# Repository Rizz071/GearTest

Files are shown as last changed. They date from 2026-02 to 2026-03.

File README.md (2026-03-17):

# GearTest

**Тестовый стенд для 3D-печатных шестерёнок**
<p align="left">
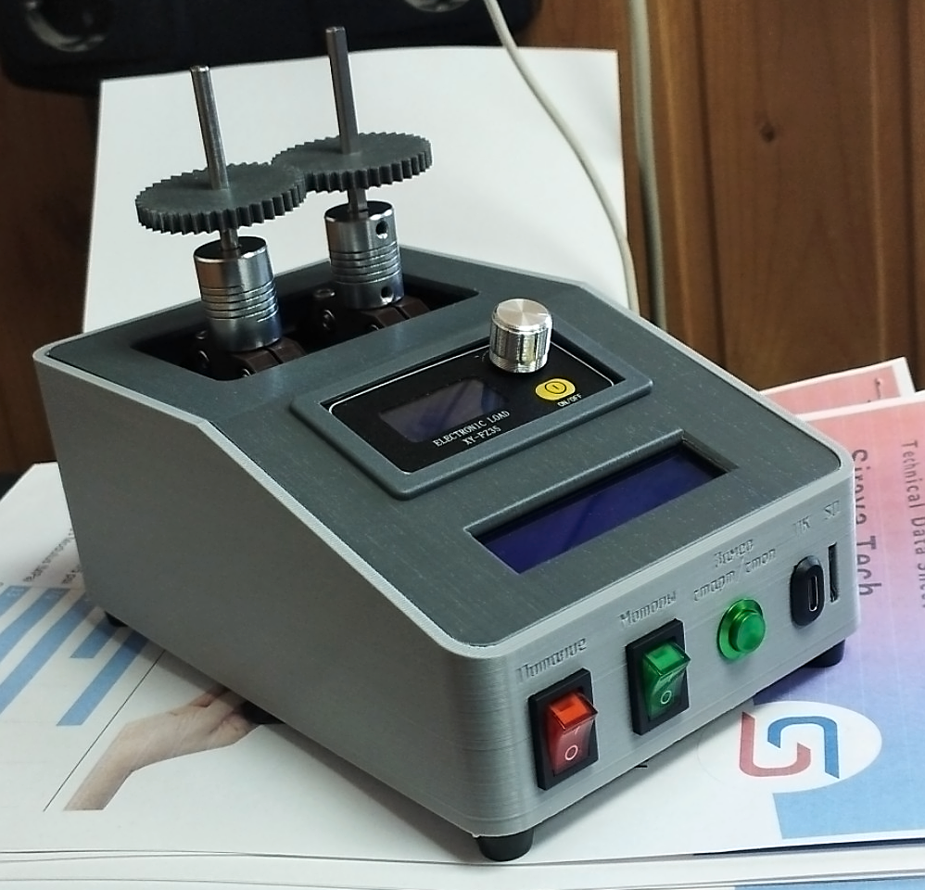
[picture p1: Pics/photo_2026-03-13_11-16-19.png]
  
</p>

---

## 🎯 О проекте

**GearTest** — это полностью открытый тестовый стенд, предназначенный для **испытания 3D-печатных шестерёнок на износ до полного отказа**.

**Главная цель**: довести пару шестерён до разрыва зацепления зубьев и точно зафиксировать момент разрушения с подробным **логированием всех параметров** в десктопное приложение на ПК.

Это позволяет объективно сравнивать долговечность разных материалов (PLA, PETG, ABS, ASA, Nylon и др.), профилей зубьев, параметров печати и постобработки.

---

## ✨ Ключевые возможности

- ✅ Автоматическая остановка при разрушении зацепления  
- ✅ Точный подсчёт времени работы до отказа  
- ✅ Логирование в реальном времени (время, нагрузка)  
- ✅ Удобное десктопное приложение для визуализации и анализа  
- ✅ Сохранение отчётов в CSV + построение графиков  
- ✅ Полностью открытый проект (hardware + software + CAD)

---

## 🛠️ Как это работает

1. В стенд устанавливается пара тестируемых шестерён  
2. Приводной мотор запускает непрерывное вращение под заданной нагрузкой  
3. Система мониторит параметры в реальном времени  
4. При разрыве зубьев (резкое изменение нагрузки/обрыв зацепления) испытание останавливается автоматически  
5. Все данные мгновенно сохраняются и отображаются в приложении на ПК

---

## 📁 Структура репозитория

```bash
GearTest/
├── CAD/          # 3D-модели стенда и шестерёнок
├── Docs/         # Полная документация, схемы, методика испытаний
├── GearTest/     # Исходный код
├── images/       # Фото и скриншоты
├── results/      # Примеры протоколов испытаний (появится позже)
└── LICENSE       # GNU GPL v3.0

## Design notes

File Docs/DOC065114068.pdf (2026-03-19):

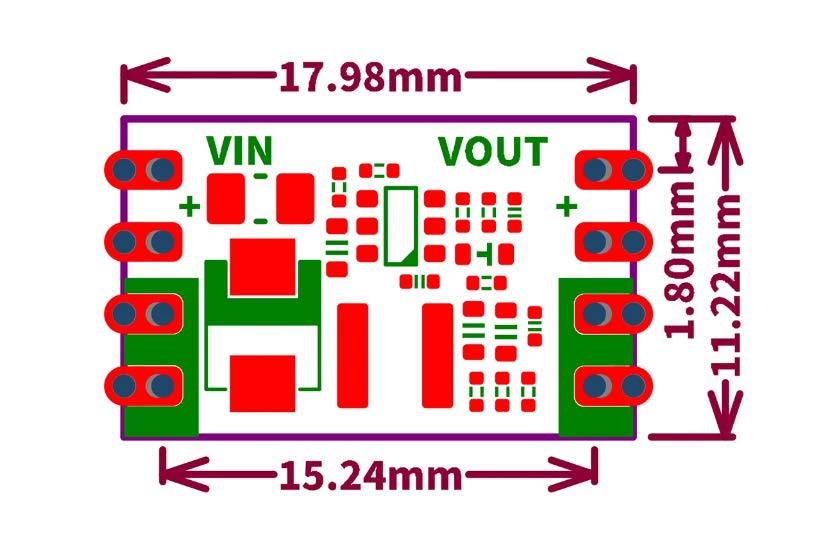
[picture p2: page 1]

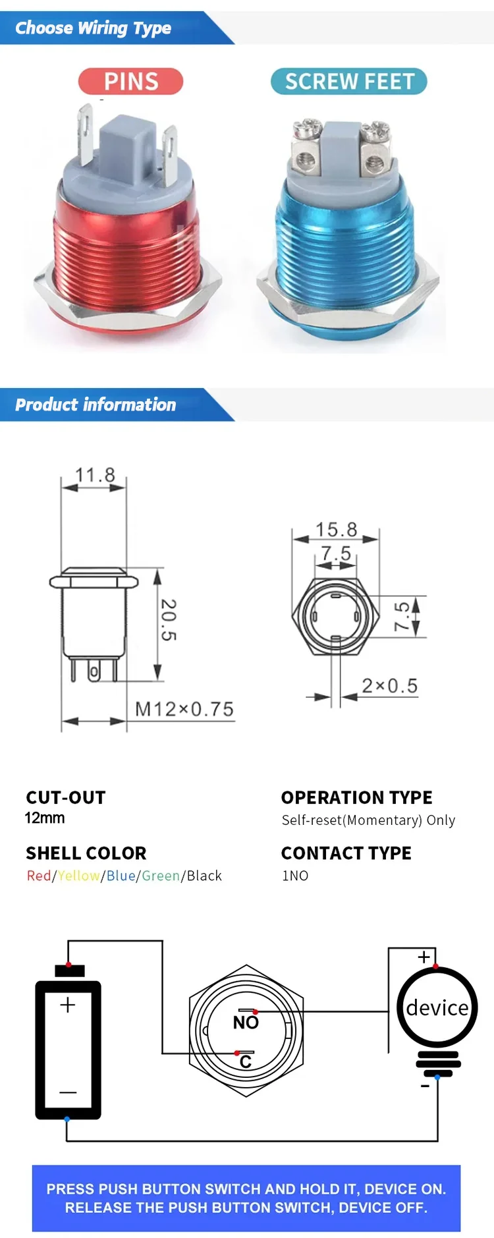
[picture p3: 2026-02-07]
Docs/Button start exper.webp

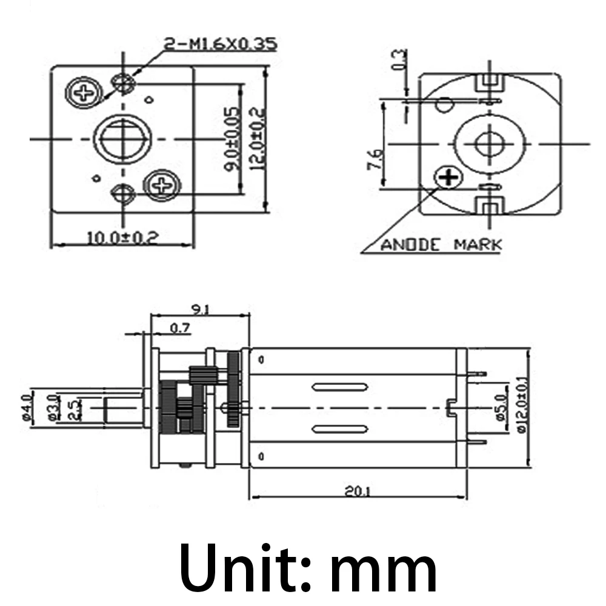
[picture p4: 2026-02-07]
Docs/Sb45f8e3612c54e4f9633423cf06d5a922.webp

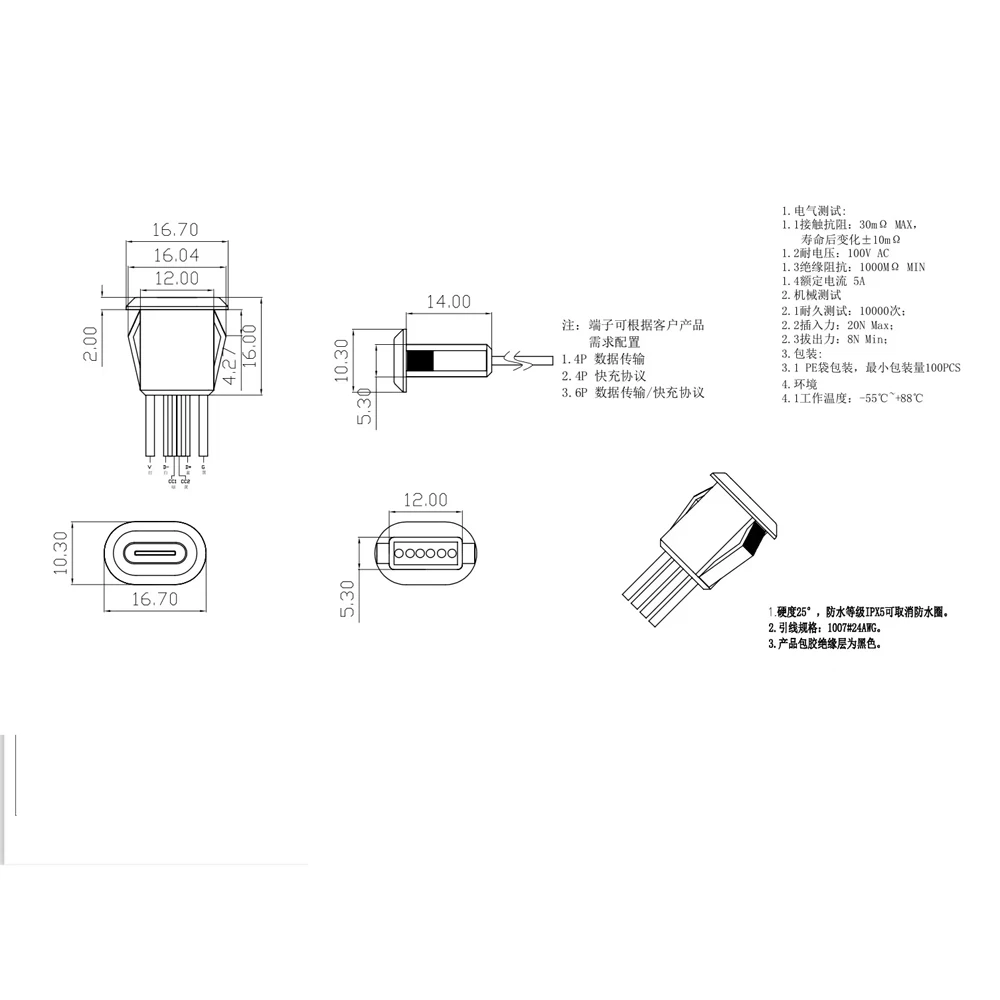
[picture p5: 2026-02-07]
Docs/Sed72e1b84ae94b2fbeed415ec35b5c65x.webp

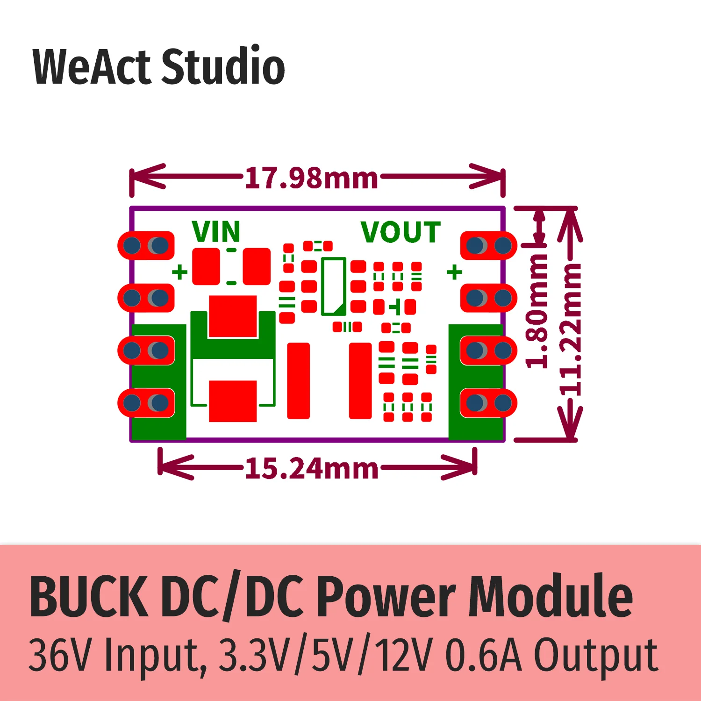
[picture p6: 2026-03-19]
Docs/S60ceae898a6440ccb248dbda5e8abc7ch.png

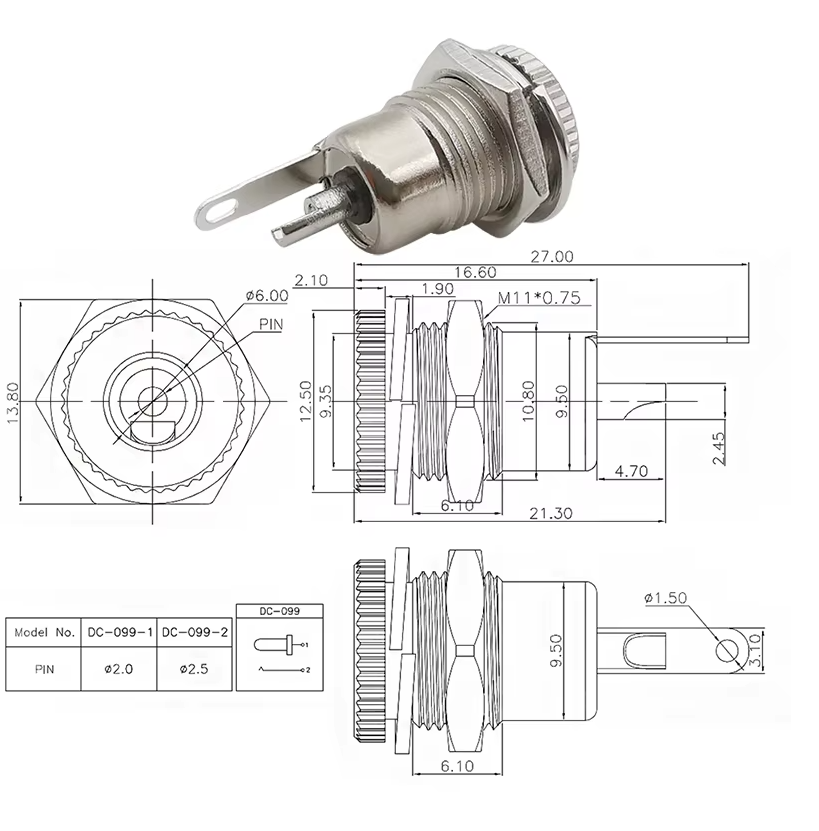
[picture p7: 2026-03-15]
Docs/fem-connector 5.5mm.png

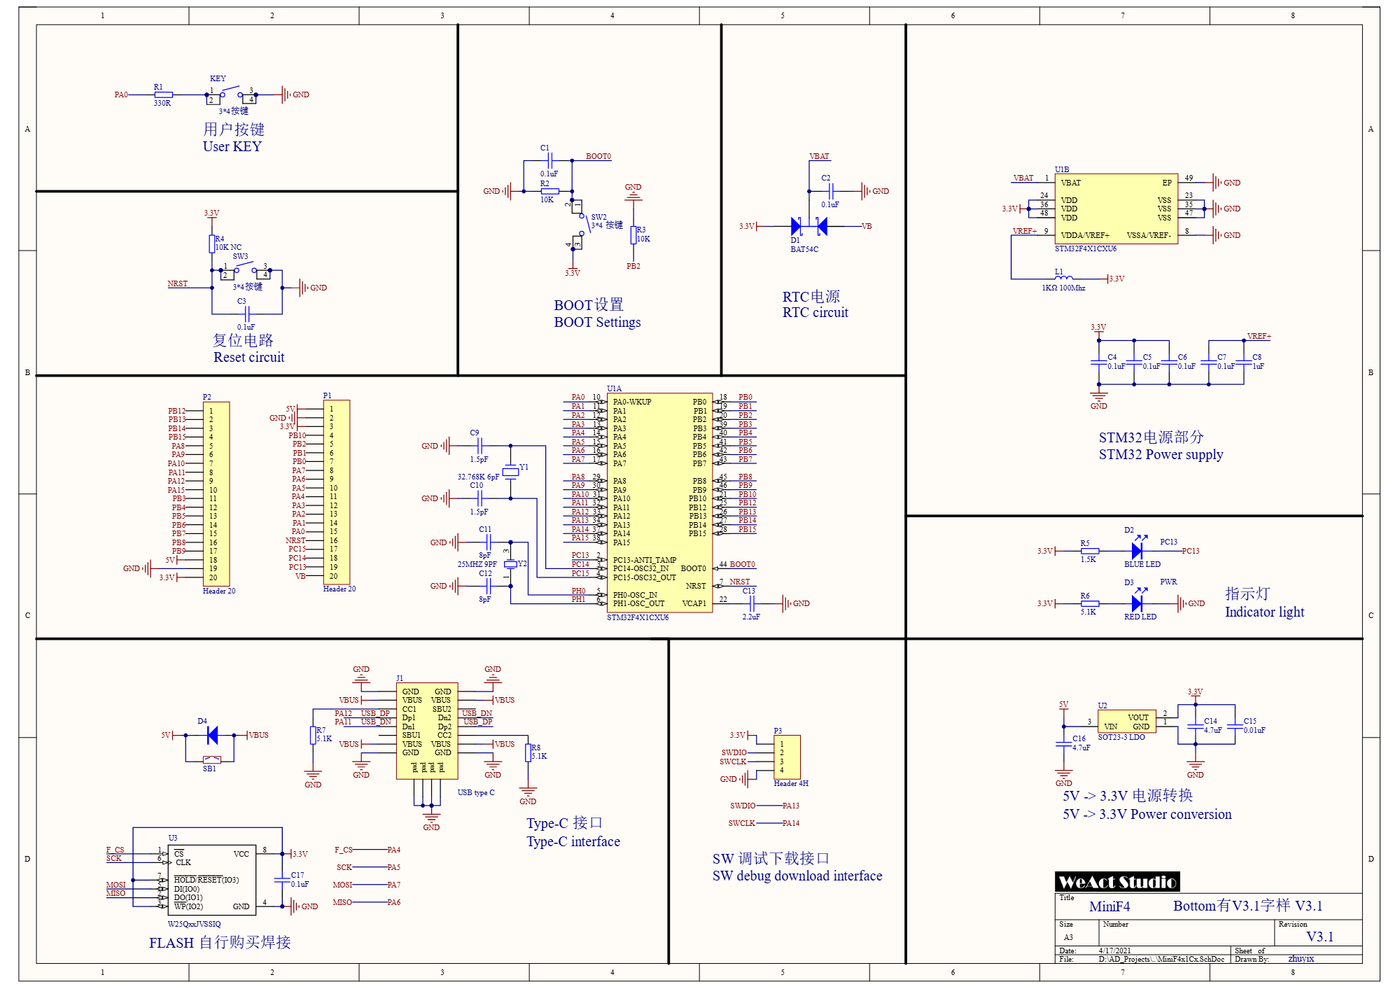
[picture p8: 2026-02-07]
Docs/Без названия.png

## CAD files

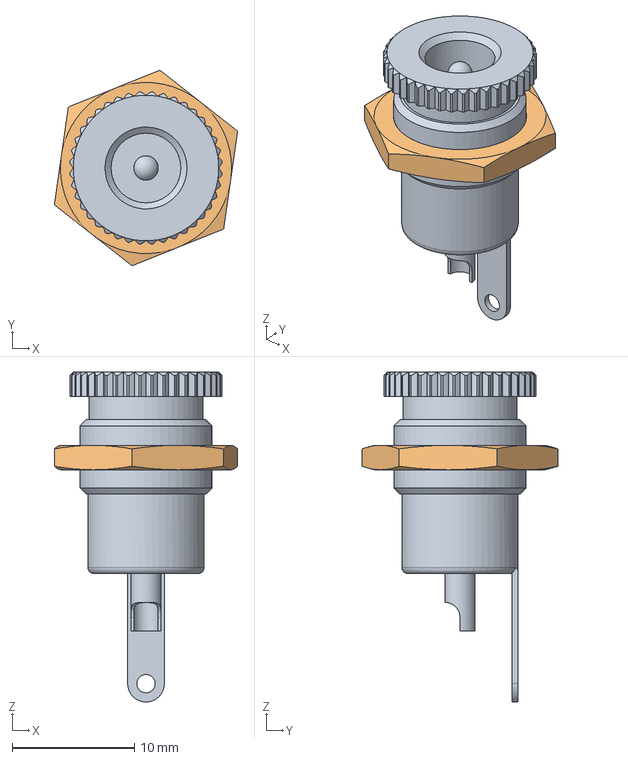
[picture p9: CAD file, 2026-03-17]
CAD/Con_5.5_Assembly.stp
15.0 x 16.0 x 27.0 mm
DC-Connector 5,5mm female
Nut M11x0.75

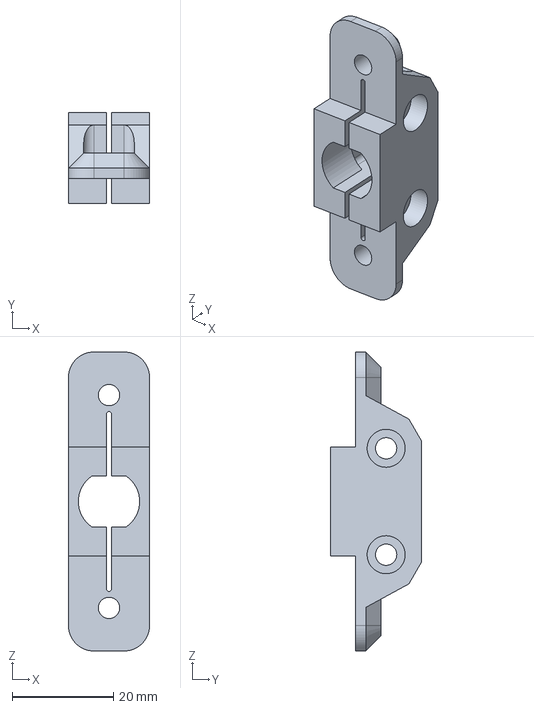
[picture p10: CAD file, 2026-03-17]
CAD/3D print/Держатель мотора скользящий-2.stp
16.0 x 18.0 x 59.0 mm

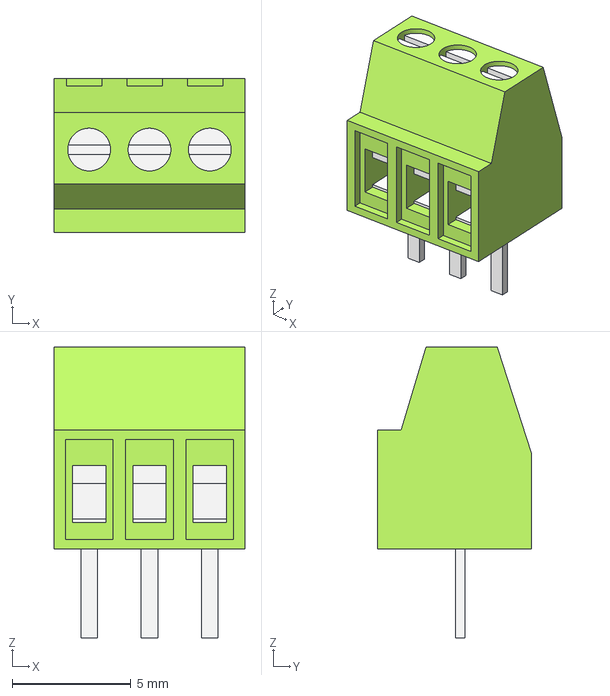
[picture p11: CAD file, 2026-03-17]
CAD/KF128-2.54-3P.step
8.02 x 6.50 x 12.3 mm
Housing
PlasticBody

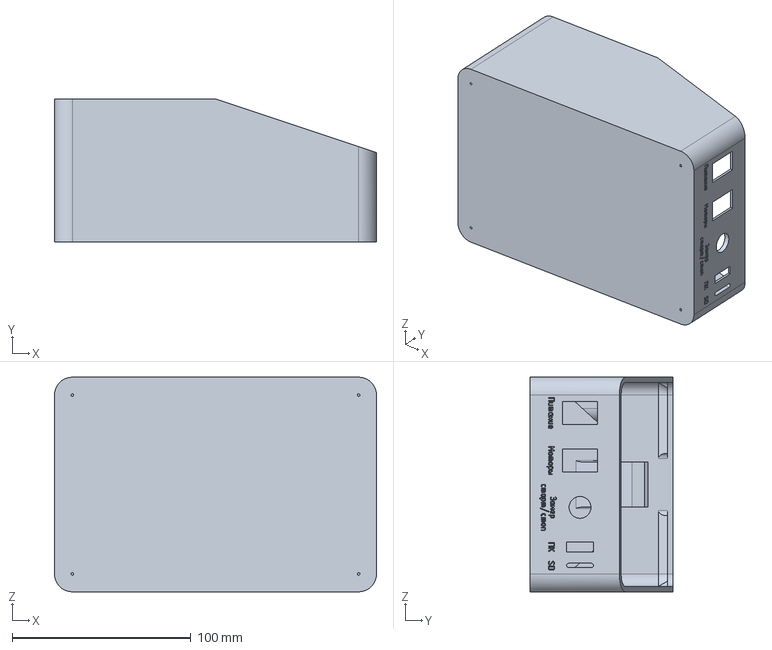
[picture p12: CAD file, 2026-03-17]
CAD/3D print/Основание корпуса.stp
180.0 x 80.0 x 120.0 mm

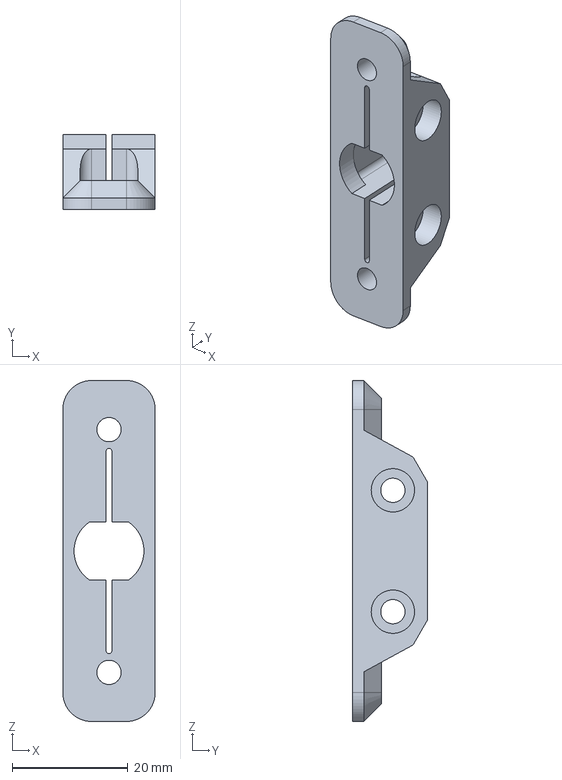
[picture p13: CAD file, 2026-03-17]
CAD/3D print/Держатель мотора скользящий.stp
16.0 x 13.0 x 59.0 mm

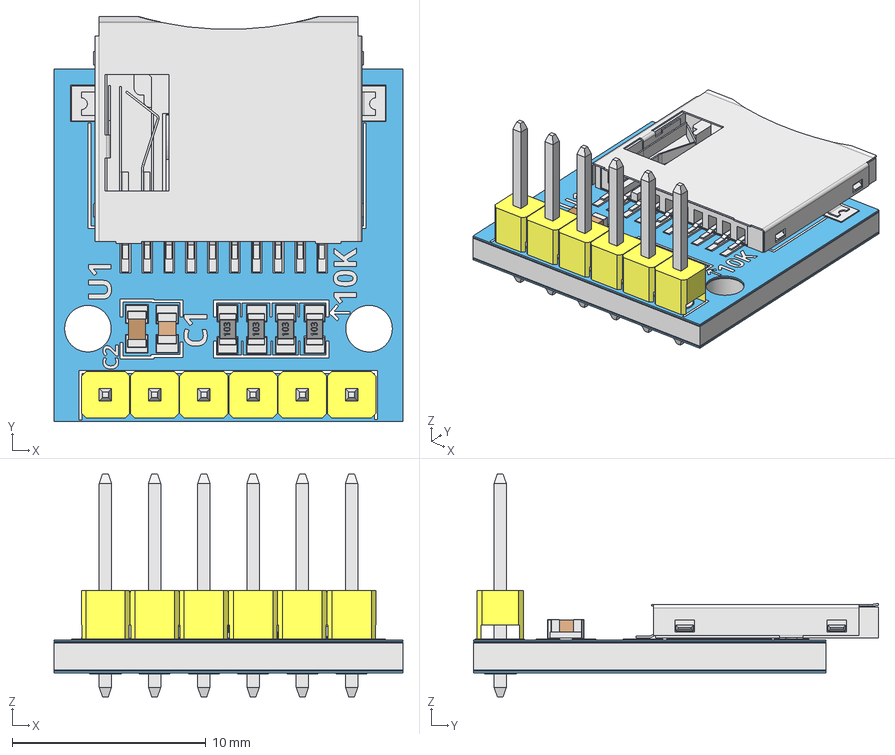
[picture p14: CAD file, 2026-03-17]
CAD/microSD_module_pls.step
18.0 x 20.9 x 11.5 mm
board_body
mask_up
mask_bt
metal_bt
metal_up
silk001
silk002
silk003
silk004
silk005
silk007
silk008
10K
U1
C1
C2
3V3
CS
MOSI
CLK001
MISO
GND001
sd_cover
conn001
conn002
conn003
conn004
conn005
conn006
conn007
conn008
conn009
conn010
pin011
label006
ShapeString009
pin012
pin013
label007
ShapeString010
pin014
pin015
label008
ShapeString011
pin016
pin017
label009
ShapeString012
pin018
contact019
contact020
contact033
contact034
Frame
Pin001
Pin002
Pin003
Pin004
Pin011
Pin012

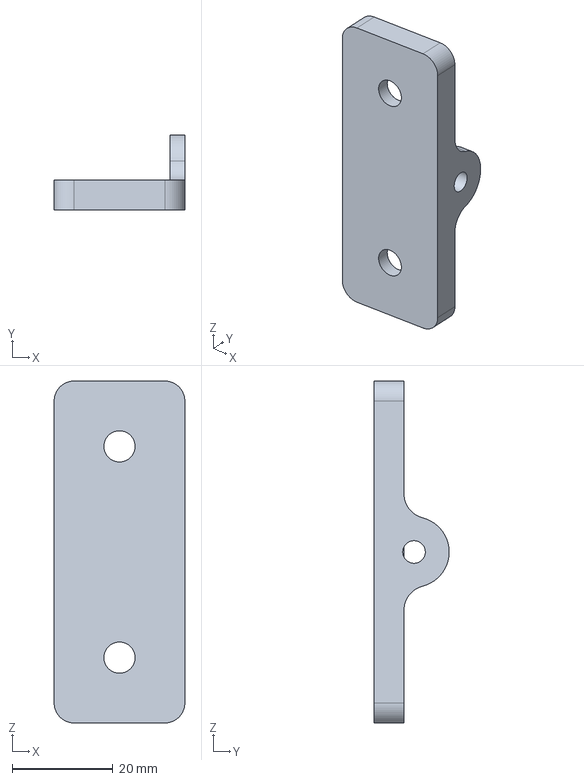
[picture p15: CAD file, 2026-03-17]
CAD/3D print/Скоба шасси.stp
26.0 x 15.0 x 68.0 mm

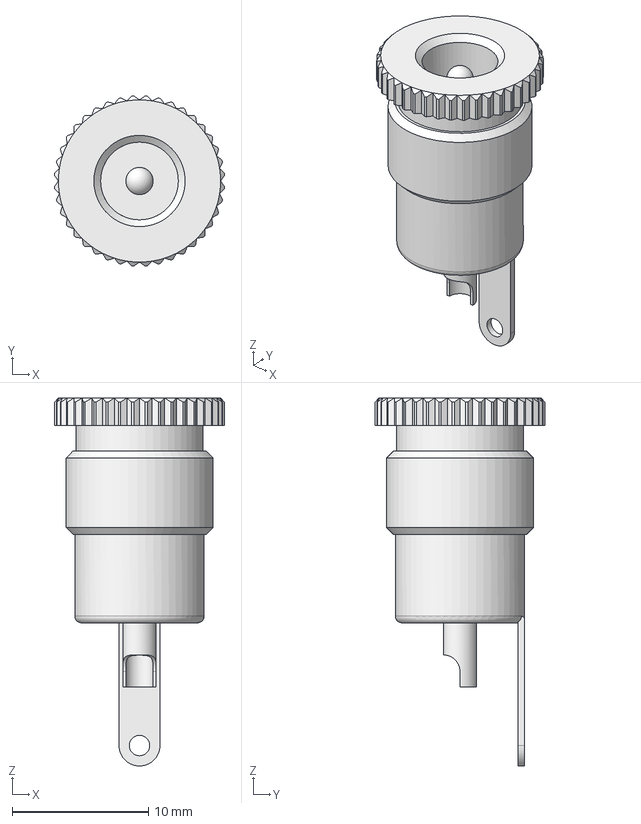
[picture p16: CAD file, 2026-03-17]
CAD/DC-Connector 5,5mm female.stp
12.5 x 12.5 x 27.0 mm

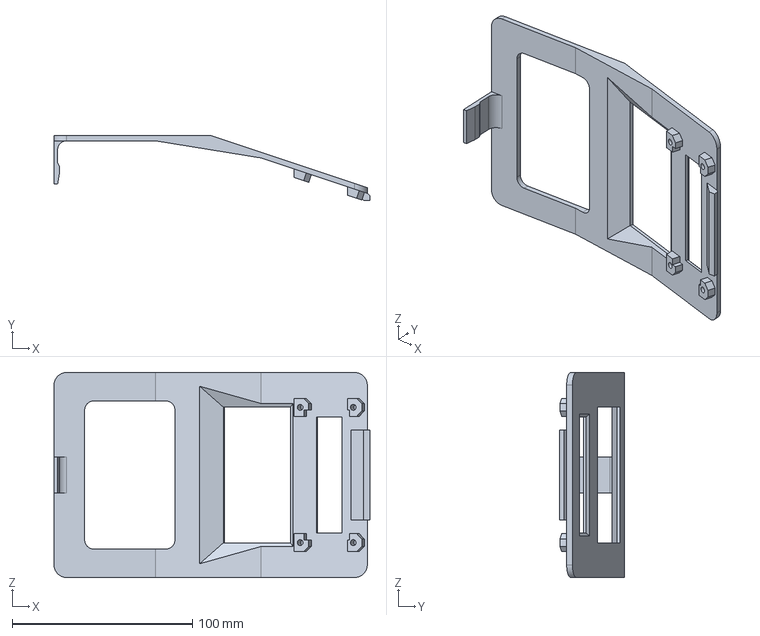
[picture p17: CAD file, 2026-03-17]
CAD/3D print/Крышка корпуса.stp
175.1 x 36.1 x 113.6 mm

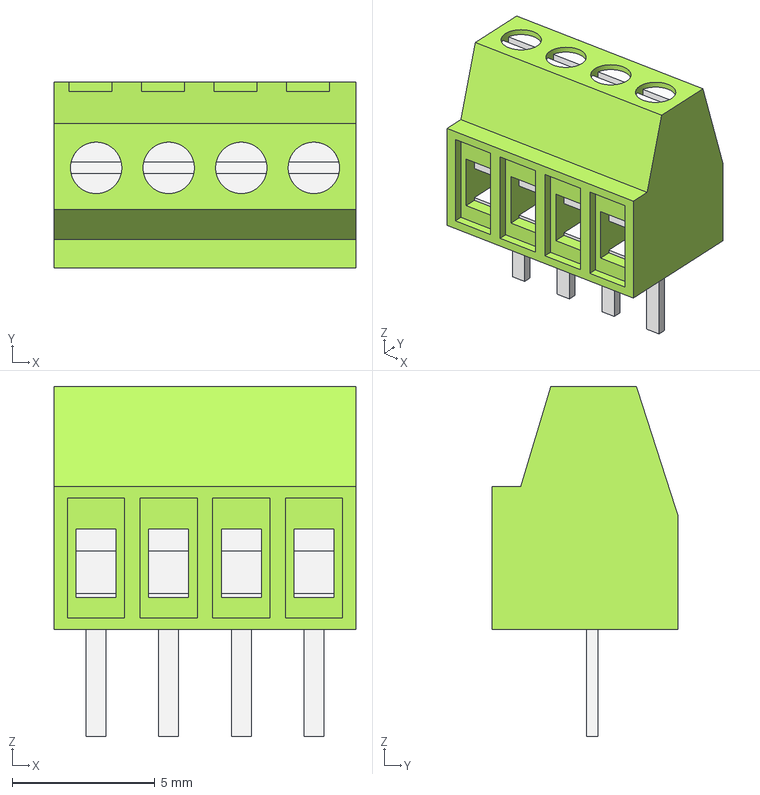
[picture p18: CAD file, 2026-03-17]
CAD/KF128-2.54-4P.step
10.6 x 6.50 x 12.3 mm
PlasticBody
Housing

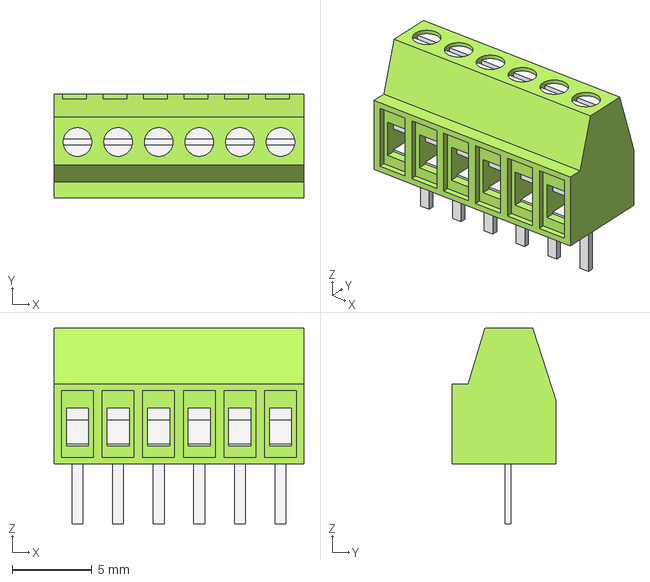
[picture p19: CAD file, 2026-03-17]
CAD/KF128-2.54-6P.step
15.6 x 6.50 x 12.3 mm
Housing
PlasticBody

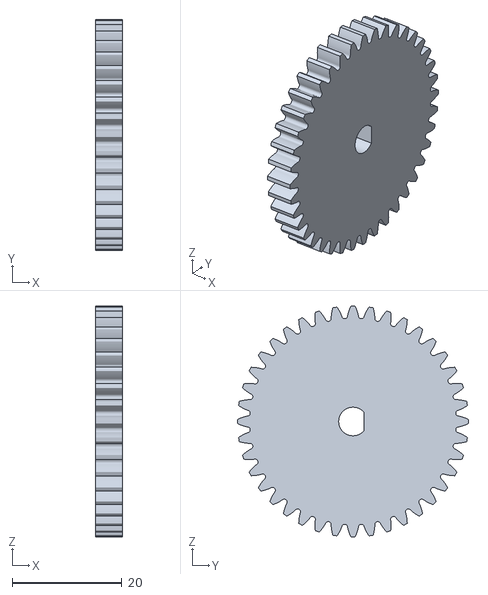
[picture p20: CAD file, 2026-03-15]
CAD/3D print/Шестерня 3 D5.stl
5.00 x 42.0 x 42.0

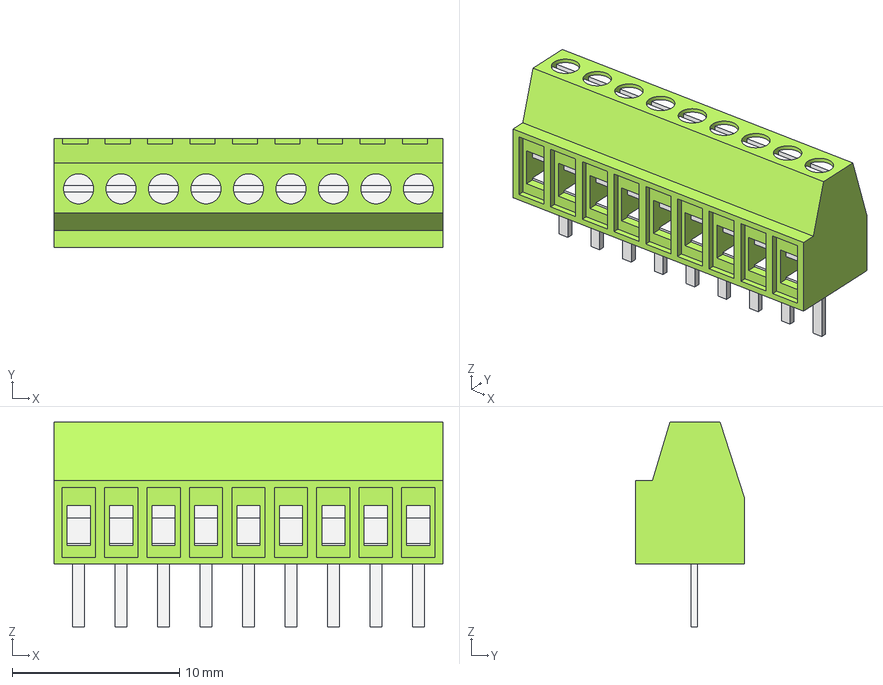
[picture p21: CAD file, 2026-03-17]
CAD/KF128-2.54-9P.step
23.3 x 6.50 x 12.3 mm
Housing
PlasticBody

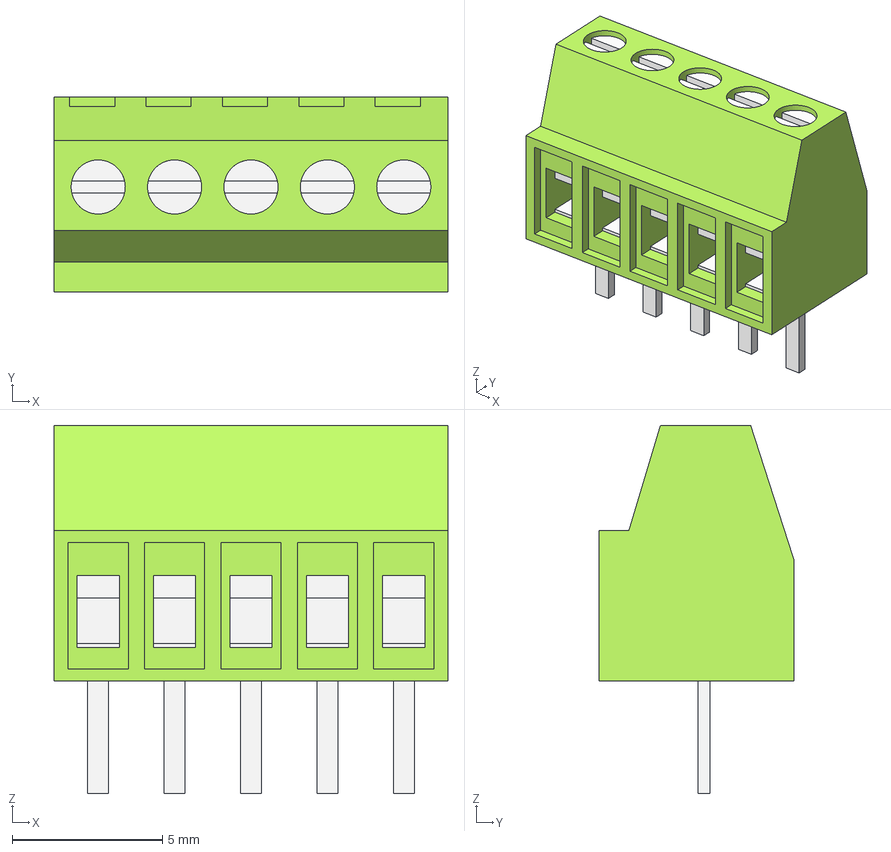
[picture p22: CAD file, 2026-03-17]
CAD/KF128-2.54-5P.step
13.1 x 6.50 x 12.3 mm
Housing
PlasticBody

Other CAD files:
CAD/3D print/Держатель мотора скользящий pet-cf.3mf
CAD/microSD_module.step
CAD/KF128-2.54-8P.step
CAD/KF128-2.54-11P.step
CAD/3D print/Держатель мотора скользящий.3mf
CAD/3D print/Крышка корпуса.3mf
CAD/3D print/Крышка корпуса.stl
CAD/3D print/Основание корпуса.3mf
CAD/KF128-2.54-10P.step
CAD/KF128-2.54-12P.step
CAD/KF128-2.54-2P.step
CAD/KF128-2.54-7P.step
CAD/LCD1602--3DModel-STEP-510211.STEP
CAD/Nut M11x0.75.stp
CAD/Rocker+Switch.skp
CAD/microSD_breakout_mini.step
CAD/microSD_breakout_mini_pins.step
CAD/microSD_module_band_pins.step

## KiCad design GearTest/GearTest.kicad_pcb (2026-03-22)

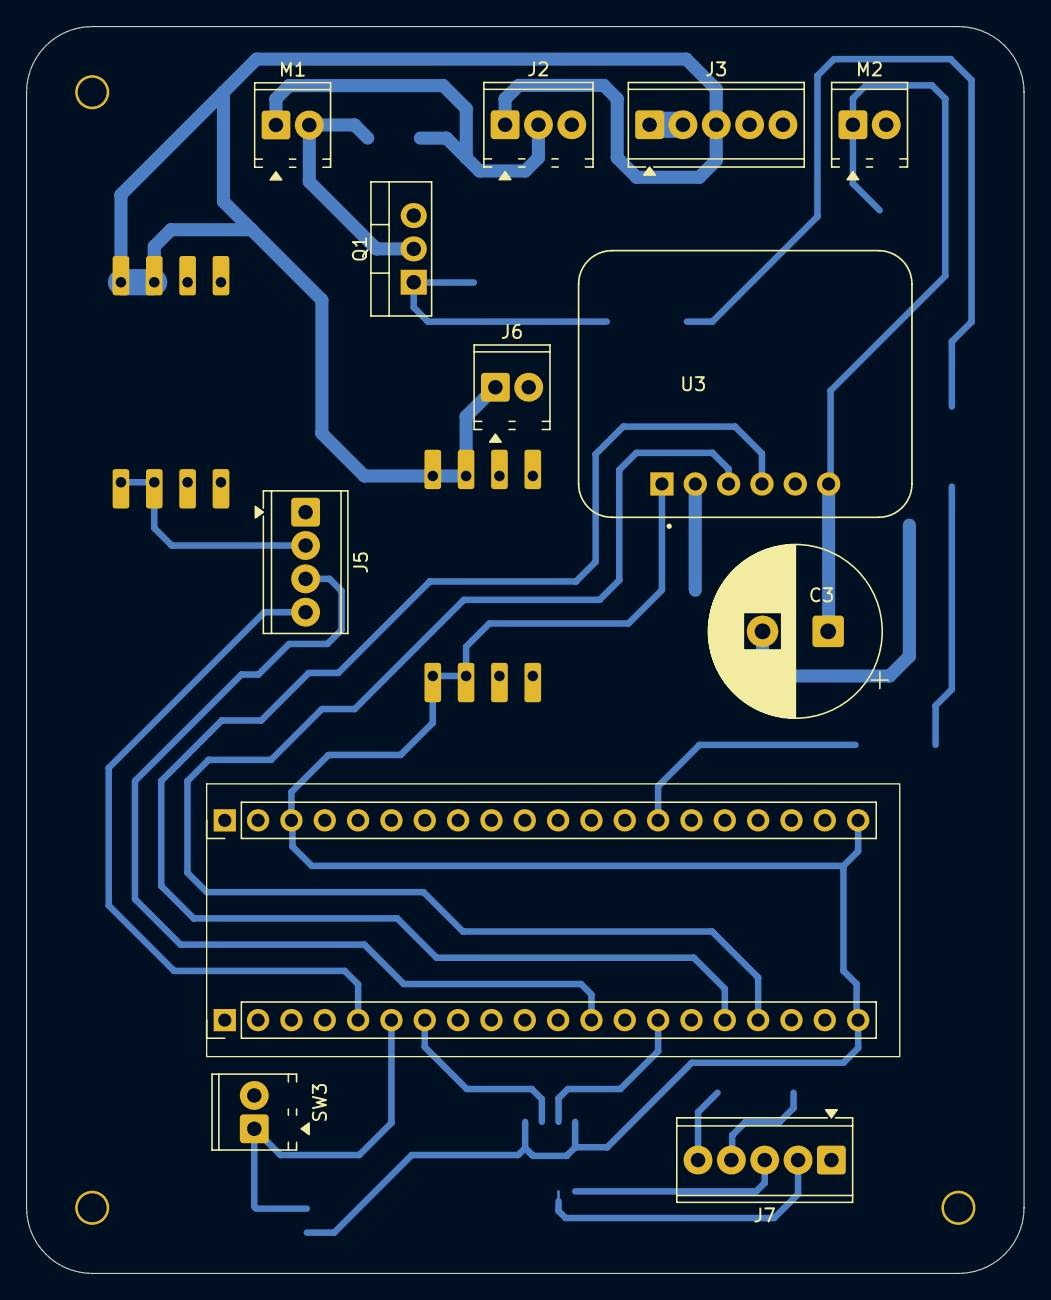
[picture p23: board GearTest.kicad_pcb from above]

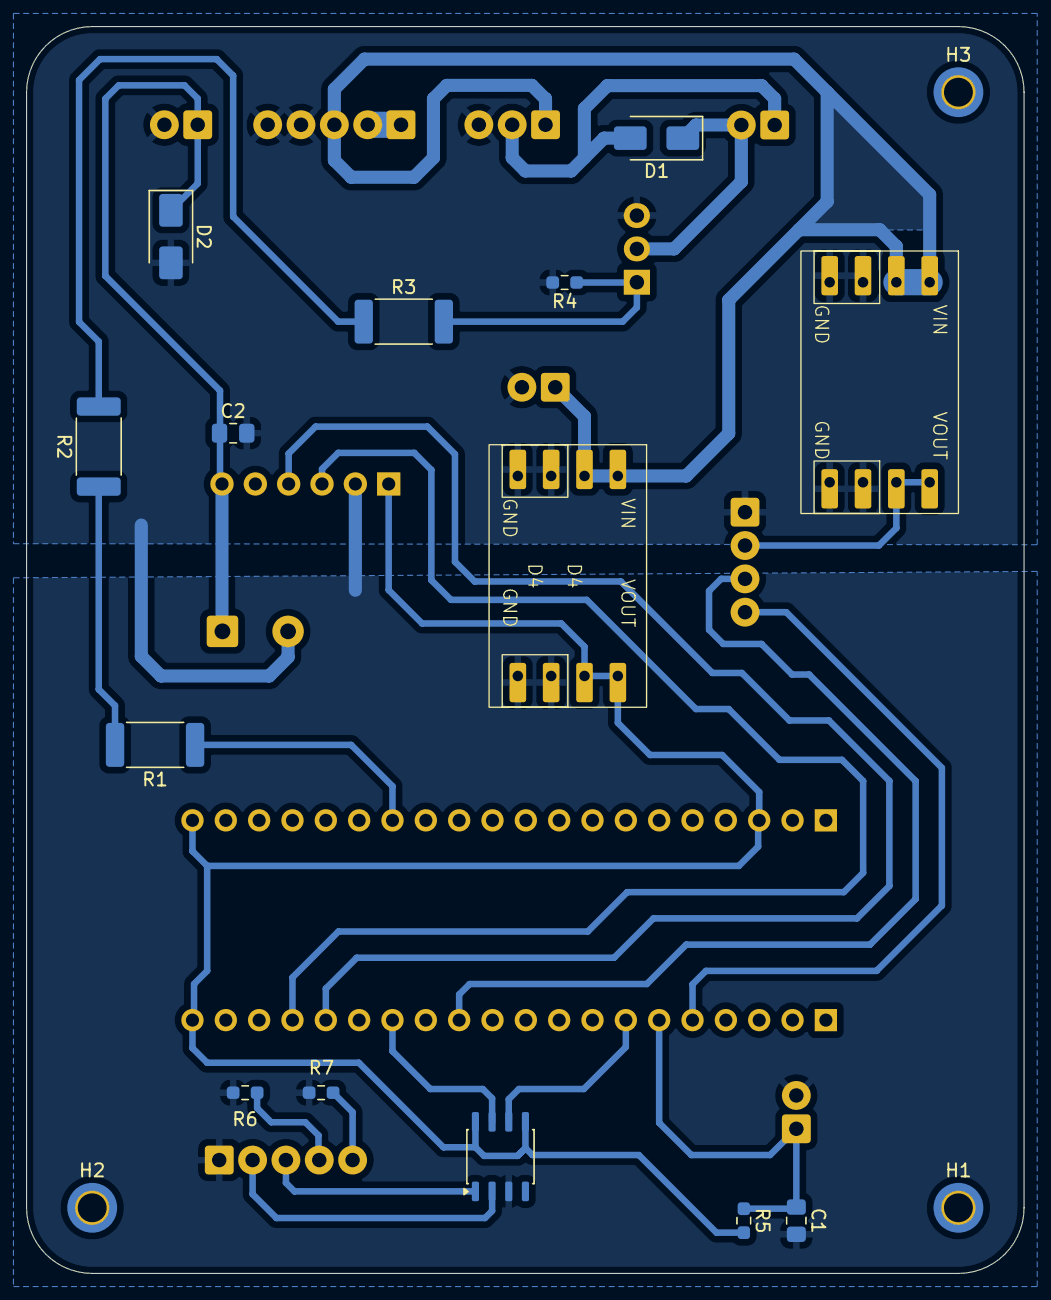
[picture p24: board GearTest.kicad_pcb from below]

Board: 2 copper layers, 76.0 x 95.0 mm, 29 parts (17 on the bottom side), 24 nets.

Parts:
C1, C2: 0.1u; C_0805_2012Metric_Pad1.18x1.45mm_HandSolder
C3: 1000u 35М; CP_Radial_D13.0mm_P5.00mm
D1, D2: SS34; D_SMA
D3, D4: WeAct DCM1 LGS5148
H1, H2, H3: MountingHole; MountingHole_2.2mm_M2_DIN965_Pad_TopOnly
J2: Терминал выключателя моторов; TerminalBlock_Phoenix_MPT-0,5-3-2.54_1x03_P2.54mm_Horizontal
J3: Терминал выключателя основного питания; TerminalBlock_Phoenix_MPT-0,5-5-2.54_1x05_P2.54mm_Horizontal
J5: Терминал LCD_1602_I2C; TerminalBlock_Phoenix_MPT-0,5-4-2.54_1x04_P2.54mm_Horizontal
J6: Терминал питания XY-FZ35; TerminalBlock_Phoenix_MPT-0,5-2-2.54_1x02_P2.54mm_Horizontal
J7: Терминал UART1; TerminalBlock_Phoenix_MPT-0,5-5-2.54_1x05_P2.54mm_Horizontal
M1, M2: Motor_DC; TerminalBlock_Phoenix_MPT-0,5-2-2.54_1x02_P2.54mm_Horizontal
Q1: IRLZ44N; TO-220-3_Vertical
R1, R2, R3: 0R; R_2512_6332Metric_Pad1.40x3.35mm_HandSolder
R4, R5: 10k; R_0603_1608Metric_Pad0.98x0.95mm_HandSolder
R6, R7: 5.1k; R_0603_1608Metric_Pad0.98x0.95mm_HandSolder
SW3: SW_Push; TerminalBlock_Phoenix_MPT-0,5-2-2.54_1x02_P2.54mm_Horizontal
U1: WeAct BlackPill STM32F411C_C-E_Ux; WeAct Blackpill
U2: CH340N; JEITA_SOIC-8_3.9x4.9mm_P1.27mm
U3: INA219

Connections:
3V3: D4.3 (VOUT), R5.2, U1.1 (VBAT), U1.60 (3V3), U2.5 (VCC), U2.8 (V3), U3.1 (VCC)
5V0: D3.3 (VOUT), J5.2
12V0: D3.1 (VIN), D4.1 (VIN), J2.1, J3.3, J6.1
/INA219_MOTOR_SCL: U1.45 (PB8), U3.4 (SDA)
/INA219_MOTOR_SDA: U1.46 (PB9), U3.3 (SCL)
/LCD1602_MOTOR_SCL: J5.4, U1.29 (PA8)
/LCD1602_MOTOR_SDA: J5.3, U1.40 (PB4)
/MOTOR_GATE: R1.1, U1.11 (PA1)
/UART1_RX: U1.31 (PA10), U2.6 (TXD)
/UART1_TX: U1.42 (PB6), U2.7 (RXD)
/USB_CC1: J7.4, R6.1
/USB_CC2: J7.5, R7.1
/USB_D+: J7.3, U2.1 (UD+)
/USB_D-: J7.2, U2.2 (UD-)
GNDD: C1.2, D4.4 (GND), J7.1, R6.2, R7.2, SW3.2, U2.3 (GND), U3.2 (GND)
GNDPWR: C2.2, C3.2, D2.2 (A), D3.2 (GND), D3.4 (GND), D4.2 (GND), J2.3, J3.4, J3.5, J5.1, J6.2, M2.2 (-), Q1.3 (S), R4.2
unnamed: D1.2 (A), J2.2, M1.1 (+)
unnamed: D1.1 (K), M1.2 (-), Q1.2 (D)
unnamed: C2.1, C3.1, D2.1 (K), M2.1 (+), U3.6 (VIN+)
unnamed: J3.1, J3.2
unnamed: Q1.1 (G), R3.2, R4.1
unnamed: R1.2, R2.1
unnamed: R2.2, R3.1
unnamed: C1.1, R5.1, SW3.1, U1.30 (PA9)

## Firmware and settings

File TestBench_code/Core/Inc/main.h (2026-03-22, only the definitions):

#define MOTOR_GATE_Pin GPIO_PIN_1
#define MOTOR_GATE_GPIO_Port GPIOA
#define LCD1602_MOTOR_SCL_Pin GPIO_PIN_8
#define LCD1602_MOTOR_SCL_GPIO_Port GPIOA
#define START_MEASURE_BUTTON_Pin GPIO_PIN_9
#define START_MEASURE_BUTTON_GPIO_Port GPIOA
#define UART1_RX_Pin GPIO_PIN_10
#define UART1_RX_GPIO_Port GPIOA
#define LCD1602_MOTOR_SDA_Pin GPIO_PIN_4
#define LCD1602_MOTOR_SDA_GPIO_Port GPIOB
#define UART1_TX_Pin GPIO_PIN_6
#define UART1_TX_GPIO_Port GPIOB
#define INA219_MOTOR_SCL_Pin GPIO_PIN_8
#define INA219_MOTOR_SCL_GPIO_Port GPIOB
#define INA219_MOTOR_SDA_Pin GPIO_PIN_9
#define INA219_MOTOR_SDA_GPIO_Port GPIOB

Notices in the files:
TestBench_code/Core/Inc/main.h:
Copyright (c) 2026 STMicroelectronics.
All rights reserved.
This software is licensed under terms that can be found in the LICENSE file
